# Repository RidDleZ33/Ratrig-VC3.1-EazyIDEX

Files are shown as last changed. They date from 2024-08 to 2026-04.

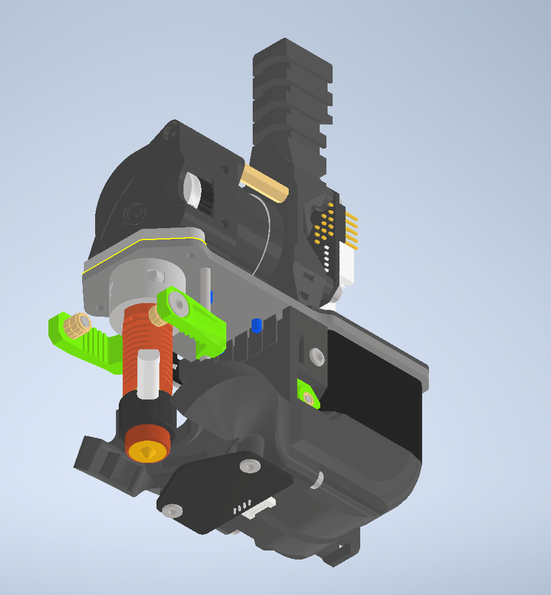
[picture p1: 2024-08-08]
RR_Toolhead_Mods/LGx_Lite_Adapter_MOD/LGx_Lite_REVO3.png

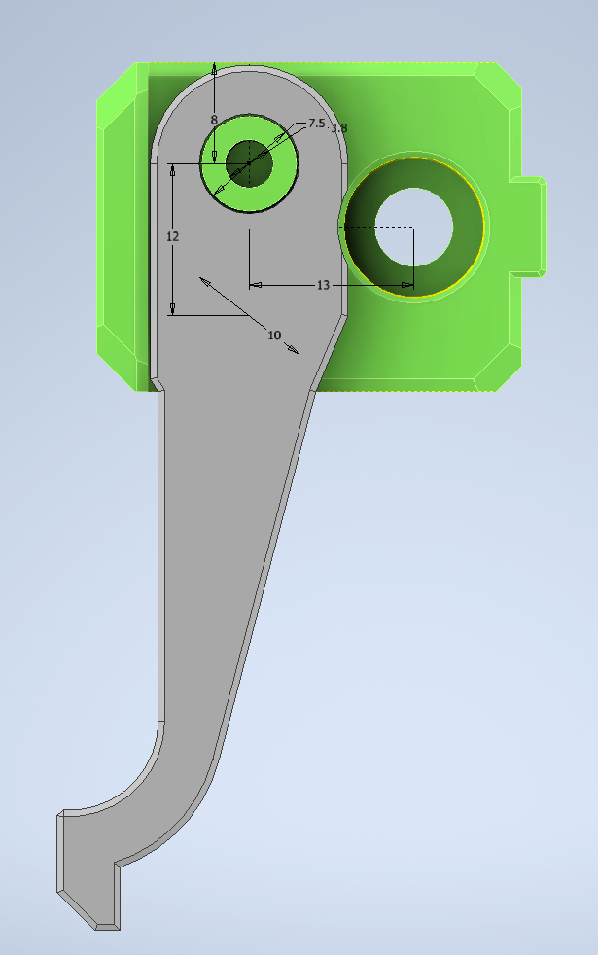
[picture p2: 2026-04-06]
Crossbow_Cutter_Mods/VC4_Depressor/vc4_y_bumper_depressor_v2_1.png

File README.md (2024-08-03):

# Ratrig-VC3.1-EazyIDEX
Modified printed parts for the RatRig V-Core 3.1 printers. Flips the hybrid Y motors to Allow IDEX to be installed without frame modification. I will have two flavors here. .

-STOCK will use modified VC3.1 joiners so the X gantry is 3.1 stock. This way you don't need any new hardware.

-3/4 HYBRID will use the joiners, modified idlers and X gantry from the new VC4 repo. Effecively giving the 3.1 a VC4 hybrid drivetrain. This way you will use all endstops, toolheads, etc from the VC4 IDEX. (note there is clearance issues with the toolhead 'vc4_back' part. I think you can use the vc3_back part from the rr toolhead upgrade repo for the 3.1. I'll update this when I know for sure)

Both options will result in loss of printing volume in the X dimension. The point of this is to easily add IDEX to current VC3.1 units wihout having to modify the frame.

For the aluminum 'plates' I resin print these in eSUN Hard Tough resin. If you can not source them I recommend this.

BOM coming at some point. Only real difference from official Enclosed Vcore 3.1 IDEX BOM is for the motor cage parts I modified:

2x M5x75 cap head screws

2x M5x45 cap head screws

2x M6x20 countersink screw

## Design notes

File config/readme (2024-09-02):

When I went through RatOS 2.1 configurator, I simply told it I have a stock VC3.1 and configured as normal.
After this, you can use my config here as a reference to add the IDEX configs/macros. Everything is done in printer.cfg. NO need to modify any other files.

Here are configs that I've used. The stockVC3.1_printer.cfg is what I use for an Octopus Pro H723. The config is set to use only 1 Y driver (use the parallel Motor2 header and swap a pin in one motor connector), however you can uncomment code and use a combination of the TFT header and EXP1 to wire in an additional driver (this is what I used, you can use any open uart and pins). Good luck!

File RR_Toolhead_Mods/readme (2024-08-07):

Here are notes and mods for the new RR toolhead.

Notes:
These are experimental. I'll update here once I've actually tried them IRL. For now it's all based on assemblies and figuring :)

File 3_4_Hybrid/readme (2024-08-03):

Print quantity notes: 1x unless specified
2x vc4_y_belt_clamp_body
2x vc4_y_belt_clamp_cap
2x vc4_x_endstop
2x vc4_xy_spacer
2x vc4_y_bumper

VC4 gantry on VC3.1

BOM:
14x M3x8 Cap Head Screw
8x M5x60 Countersink Screw
2x M5x30 Low Profile Screw
4x M4x20 Cap Head Screw
4x M4x6 Set Screw
4x M6x12 Cap Head Screw
4x M6 Drop in nut for 3030

6x M3x30 Cap Head Screw

16x F695ZZ Ball Bearing
8x 695ZZ Ball Bearing 
8x M3 Washer
6x M3x4.6x4 Brass Heat Insert

4x M5x22 Countersink Screw

RR toolhead LGx W/REVO
4x M3x6.5 Countersink Screw
4x M3x12 Countersink Screw

VC4 Idler height set: 31.5mm from top of Y belt to top of Alum Extrusion

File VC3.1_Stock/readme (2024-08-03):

Notes:
Parts in the 'Alum' folder are aluminum parts. If you're in a pinch, I found they can be resin printed.

Quantity notes:
2x vc3_idex_motor_plate_v1.0 v2.stl (in Alum folder)
2x PP000128-x_endstop_block_3.1_V01_20230703.stl (If you're upgrading from a non-idex: 1x)

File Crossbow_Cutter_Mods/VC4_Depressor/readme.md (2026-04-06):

# vc4_y_bumper_depressor

Depressor made from modified VC4 Y bumper. use a small washer with the M4 to keep the lever on the body.
on IDEX machines there's plenty of 'room for activities' on either side of the print surface.
the depressor on this is magnetic, this way we can home and probe as usual and the lever simply pushes out of the way.
When a cut opperation needs to happen, simply make a gcode macro that goes around and pull the crossbow lever.
disclaimer, be sure the order of homing, etc never comes at the lever from the depressing side.
Usually this isn't a probem because of the extra space on IDEX. extra caution on non idex machines.

BOM:
2x 10x4 magnets (common ratrig enclosure panel mounting, etc.)
1x M4x6mm ~ fastener

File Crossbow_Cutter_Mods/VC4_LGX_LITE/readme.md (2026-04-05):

# Crossbow CNC VC4_LGX_LITE_UNI

Modified crossbow body and holder for Ratrig VC4 LGX Lite adapter toolheads. Simply buy a CNC crossbow and put all hardware on this printed variant.
Handle can be mounted on either side for T1 or T0 heads. Still easilly replace razor. printed in PETG and have over 100 cuts with no issues so far, though I plan to print in Nylon eventually.
requires one extra part: M2.5 x 5mm ~ fastener for handle. I've used countersunk and caphead, doesn't matter. just needs to hold the sandwich together at the handle for less flex.

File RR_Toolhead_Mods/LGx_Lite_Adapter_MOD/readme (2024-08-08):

This plate will adapt an LGx_Lite extruder to the new RR toolhead.

BOM:
1x adapter (I resin printed it, but I'm sure you could FDM print)
1x toolboard_vertical mount for attaching to extruder
1x M3x30 cap head screw for enough thread to screw on standoff
1x M3x8 cap head screw for attaching toolboard mount to standoff
4x M3x8 countersink head screws
2x M3x8 cap head screws (stock ones for mounting orbiter)

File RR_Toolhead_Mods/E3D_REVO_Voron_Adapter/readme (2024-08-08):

This plate mounts the E3D REVO hotend on the new RR toolhead. Luckily the REVO heatbreak is so much shorter than the rapido, that there's room to use the space to make an adapter.

BOM:
1x REVO_Adapter
4x M2.5x12 countersink head screws
4x M2.5 Nylock Hex Nut
4x M3x18 countersink head screws

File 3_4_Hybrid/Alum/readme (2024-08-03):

Parts here are Aluminum. You can also resin print them. I recommend eSUN Hard Tough Resin.

Quantity notes:
1x EazyIDEX tensioner body left
1x EazyIDEX tensioner body right
2x vc3_idex_motor_plate
4x vc4_tensioner_arm
2x vc4_xy_joiner_lower
2x vc4_xy_joiner_middle
2x vc4_xy_joiner_upper

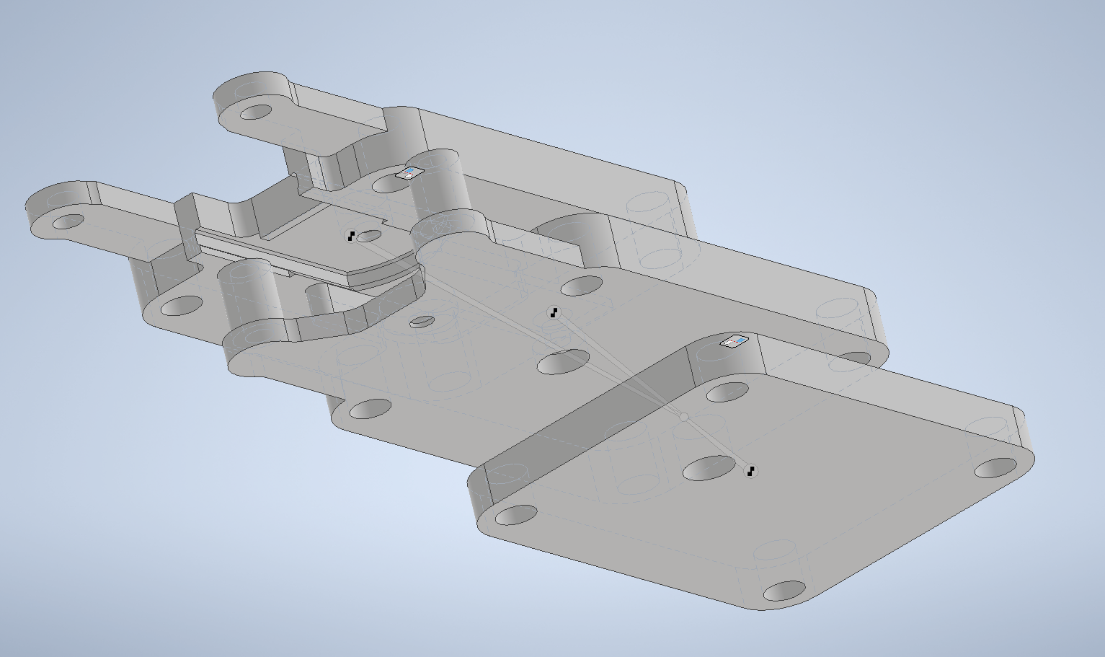
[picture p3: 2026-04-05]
Crossbow_Cutter_Mods/VC4_LGX_LITE/Cutter_VC4_LGX_LITE_ASSY3.png

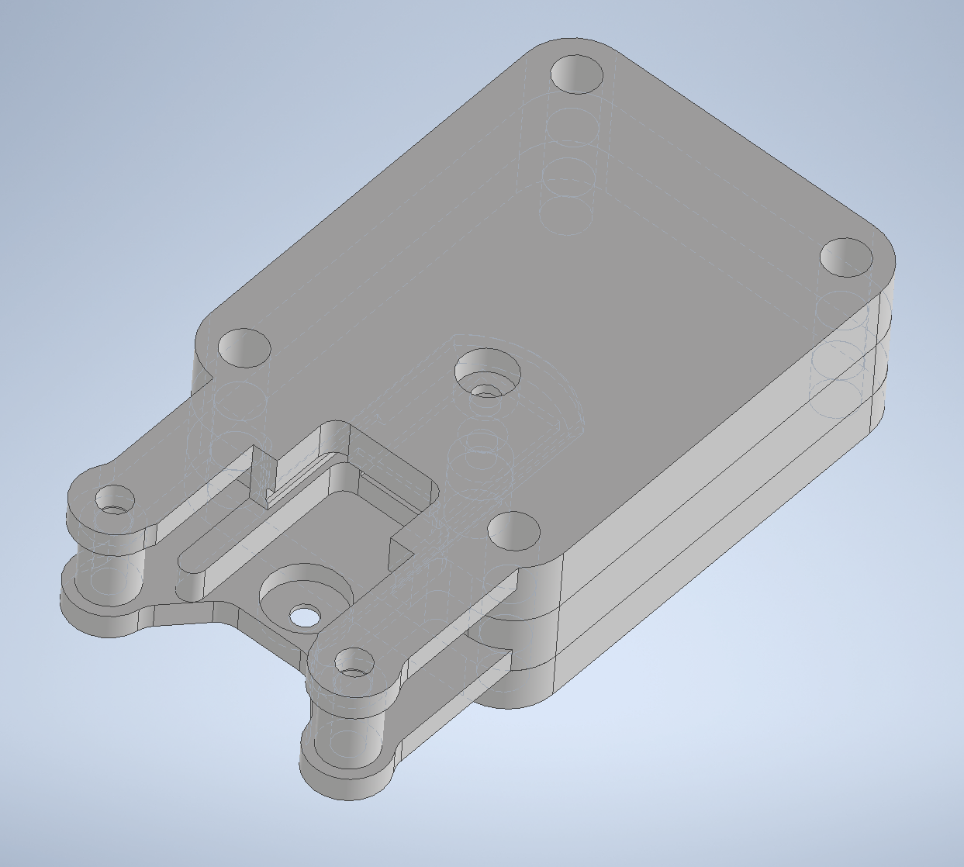
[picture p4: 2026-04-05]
Crossbow_Cutter_Mods/VC4_LGX_LITE/Cutter_VC4_LGX_LITE_ASSY1.png

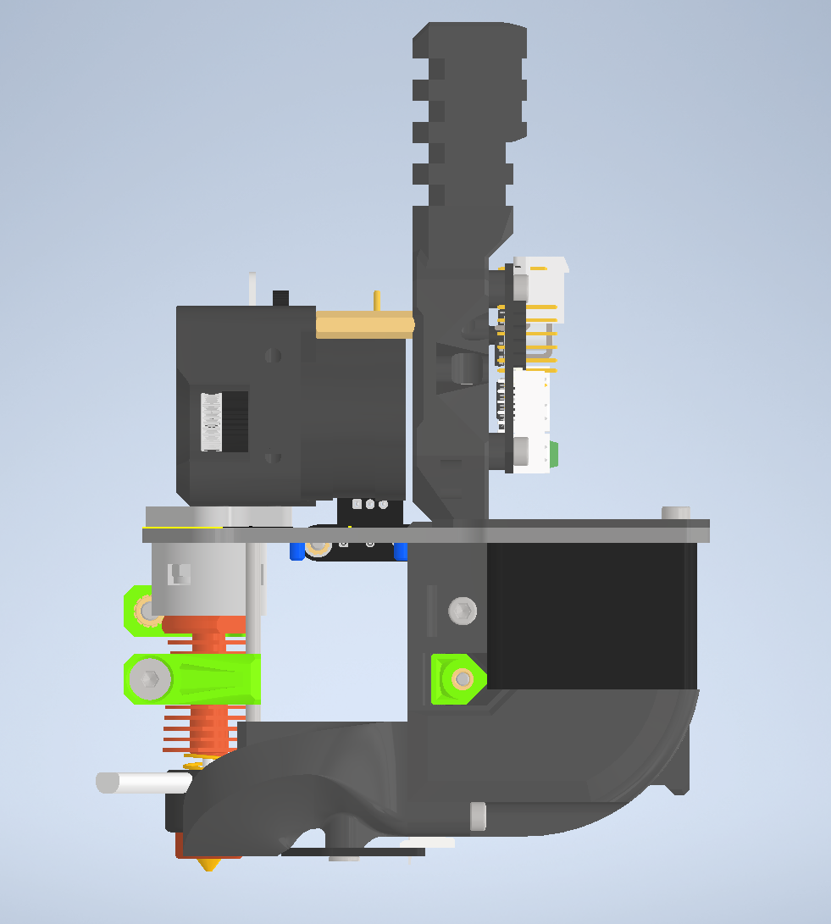
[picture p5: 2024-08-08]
RR_Toolhead_Mods/LGx_Lite_Adapter_MOD/LGx_Lite_REVO2.png

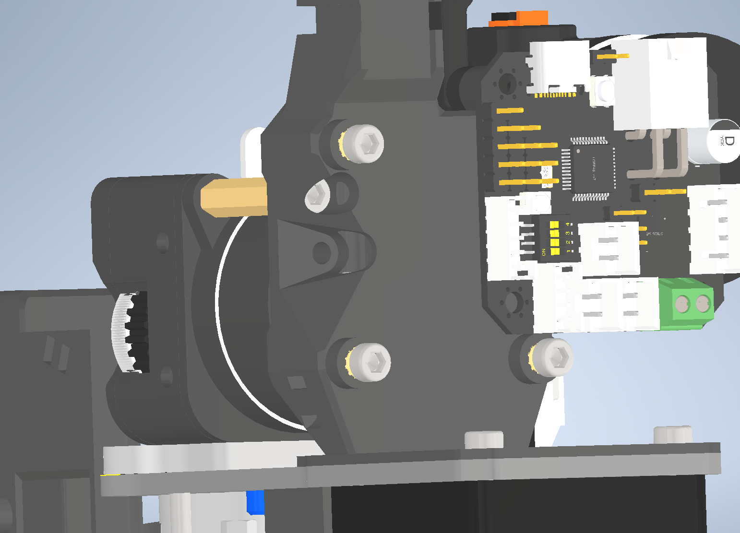
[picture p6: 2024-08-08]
RR_Toolhead_Mods/LGx_Lite_Adapter_MOD/LGx_Lite_ToolboardMnt.png

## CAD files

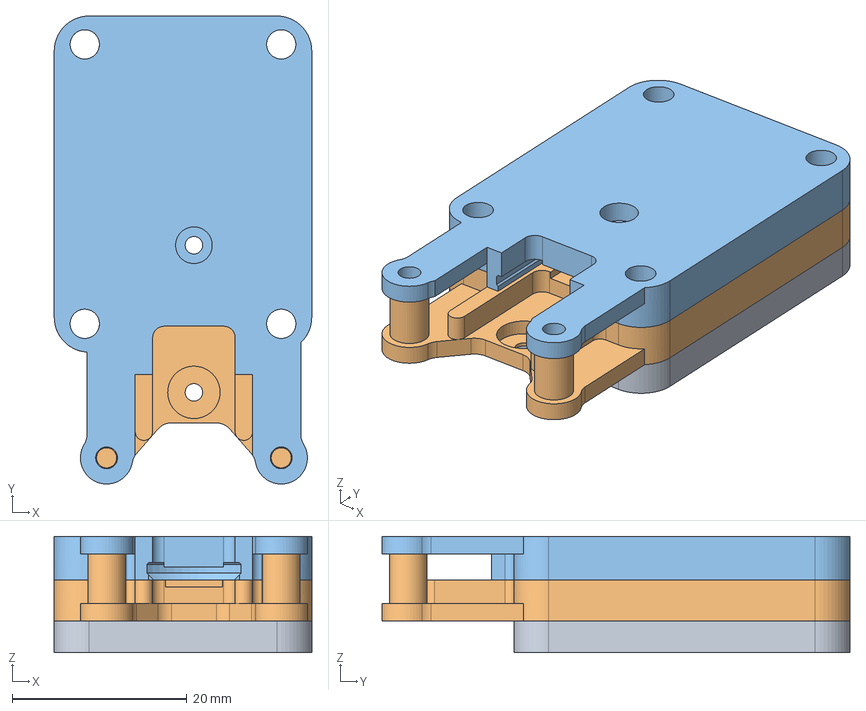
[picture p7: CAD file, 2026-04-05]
Crossbow_Cutter_Mods/VC4_LGX_LITE/cad/Crossbow CNC VC4_LGX_LITE_UNI_V2_assy.stp
29.5 x 53.6 x 13.3 mm
Crossbow CNC VC4_T1_spacer_v2
Crossbow CNC VC4_T1_Assy_simplified_V2
Crossbow CNC VC4_T1_holder_V2

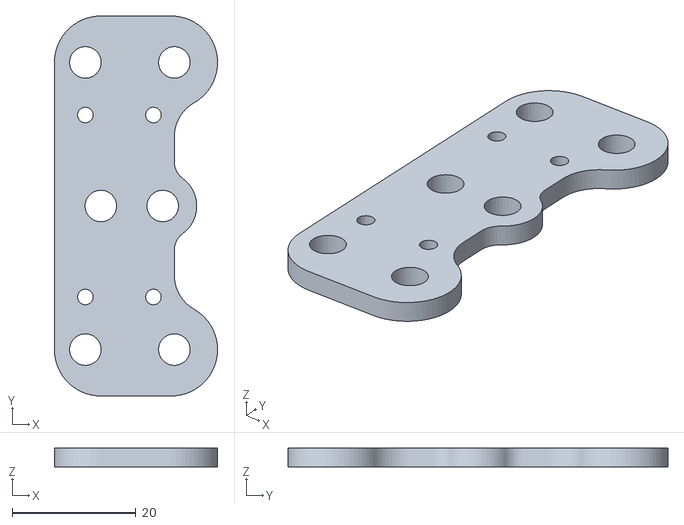
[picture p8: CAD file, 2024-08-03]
3_4_Hybrid/Alum/vc4_xy_joiner_lower_v1.1 v1.stl
26.4 x 61.4 x 3.00

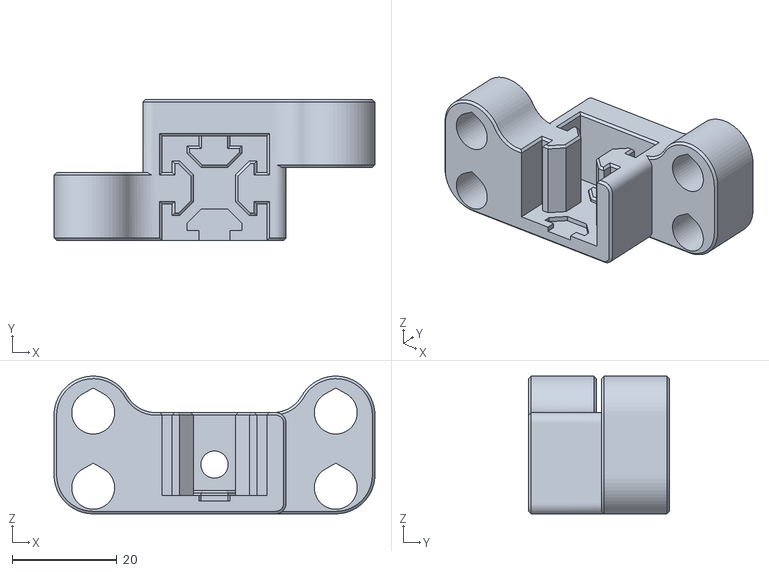
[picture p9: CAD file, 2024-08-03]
3_4_Hybrid/vc4_xy_spacer v2.stl
61.4 x 27.0 x 26.4

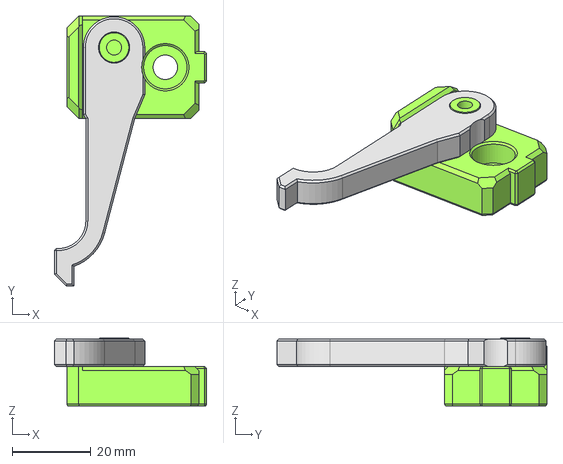
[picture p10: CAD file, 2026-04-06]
Crossbow_Cutter_Mods/VC4_Depressor/cad/vc4_y_bumper_depressor_v2.stp
38.7 x 68.5 x 17.2 mm

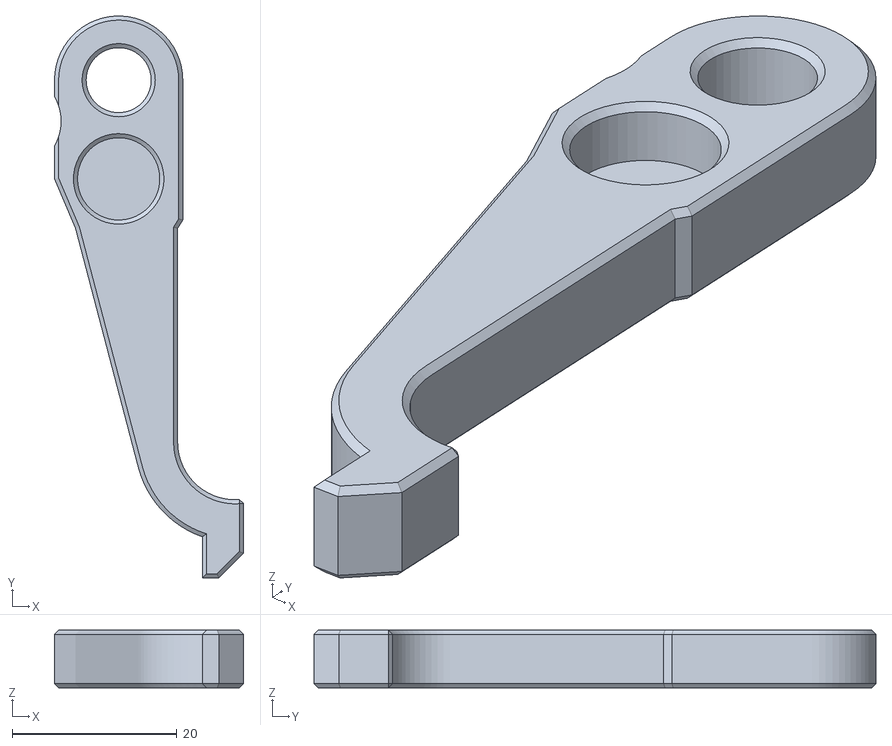
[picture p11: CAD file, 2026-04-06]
Crossbow_Cutter_Mods/VC4_Depressor/vc4_y_bumper_depressor_lever_v2.stl
23.0 x 68.3 x 7.00

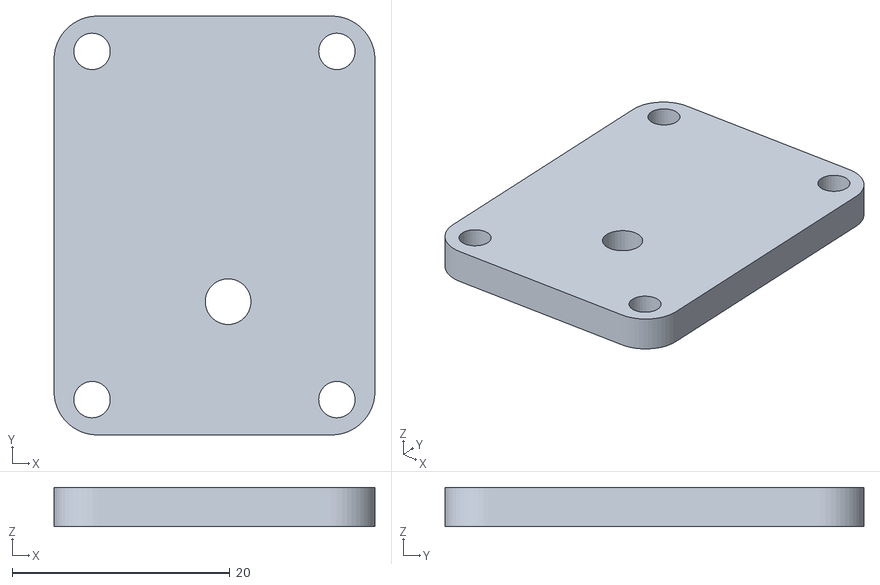
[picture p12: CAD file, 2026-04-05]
Crossbow_Cutter_Mods/VC4_LGX_LITE/Crossbow CNC VC4_LGX_LITE_UNI_V2_Spacer.stl
29.5 x 38.5 x 3.60

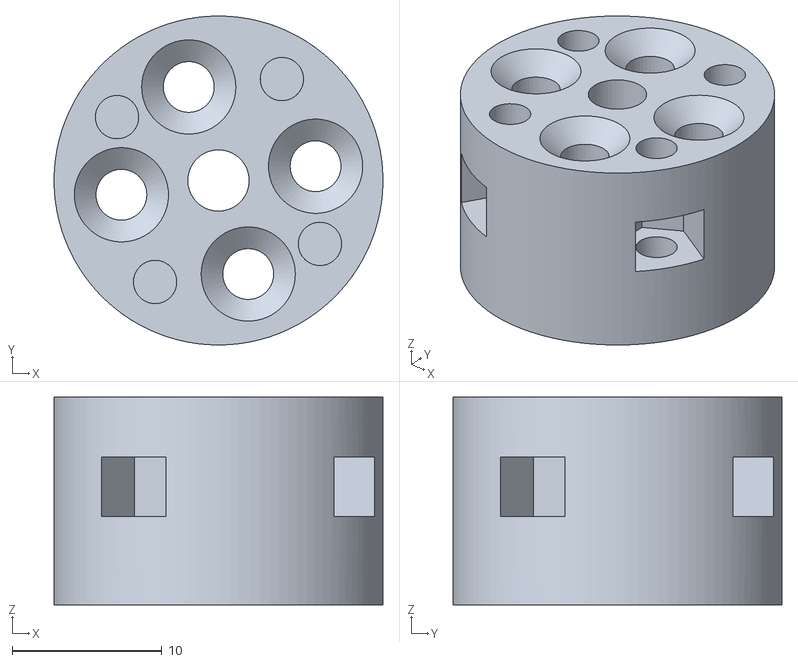
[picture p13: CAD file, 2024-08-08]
RR_Toolhead_Mods/E3D_REVO_Voron_Adapter/Revo_Voron_RR Toolhead Adapter.stl
22.0 x 22.0 x 13.9

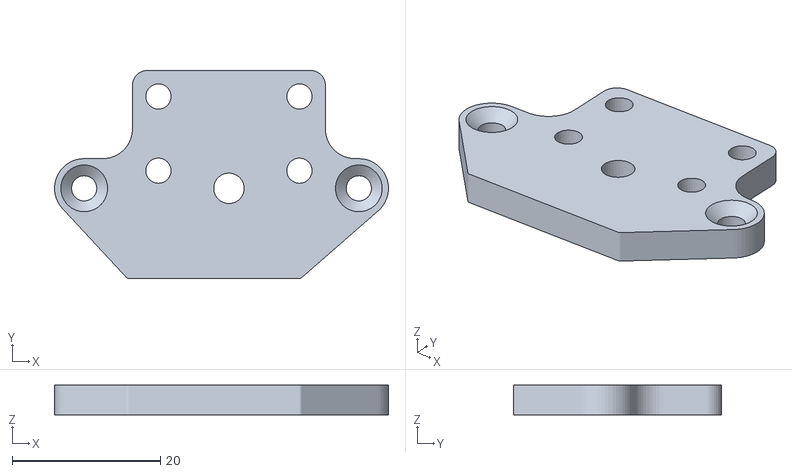
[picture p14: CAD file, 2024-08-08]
RR_Toolhead_Mods/LGx_Lite_Adapter_MOD/LGx_Lite_Adapter_RR Toolhead Plate.stl
45.0 x 28.0 x 4.00

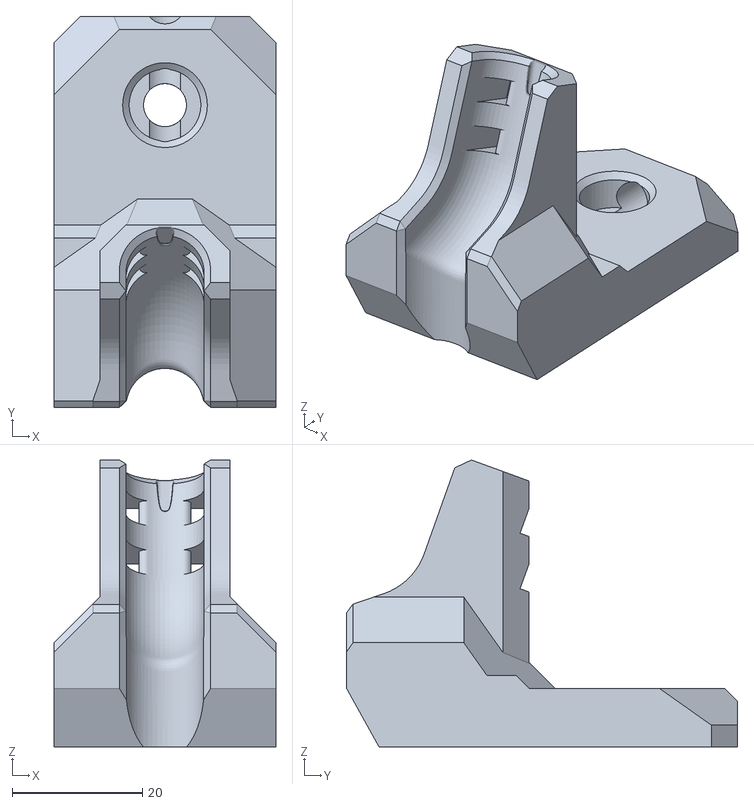
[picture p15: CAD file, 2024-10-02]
VC3.1_Stock/vc4_vc3_MOD_umbilical_frame.stl
34.0 x 60.0 x 44.0

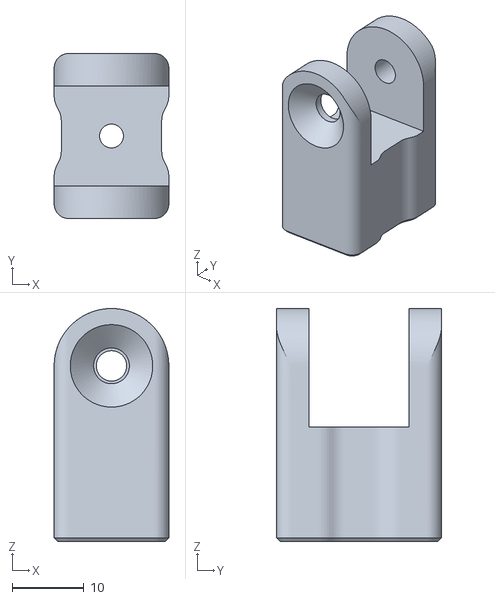
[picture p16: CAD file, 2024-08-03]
3_4_Hybrid/Alum/vc4_tensioner_arm_v1.0 v1.stl
16.0 x 23.0 x 32.5

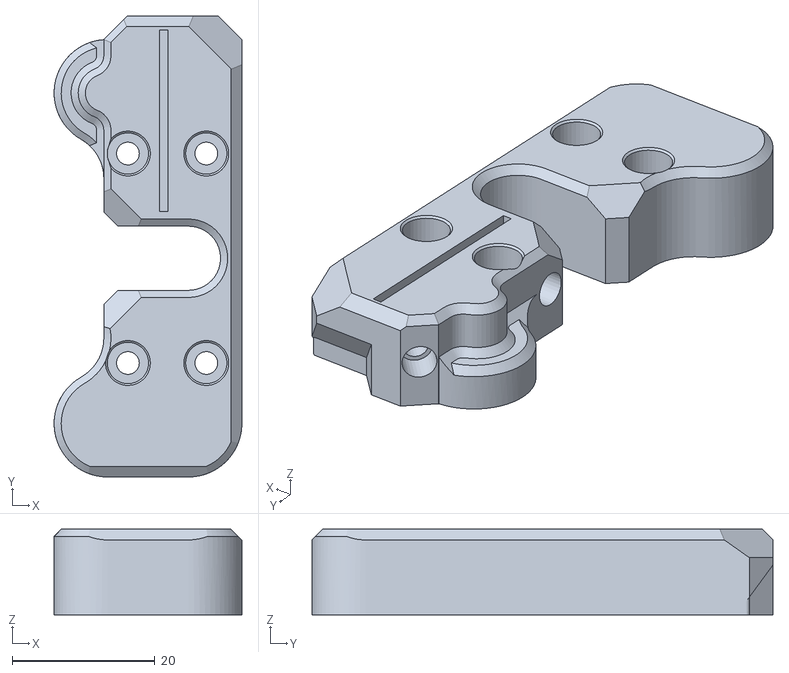
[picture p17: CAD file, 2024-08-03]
3_4_Hybrid/vc4_xy_trim_right.stl
26.4 x 64.7 x 12.0

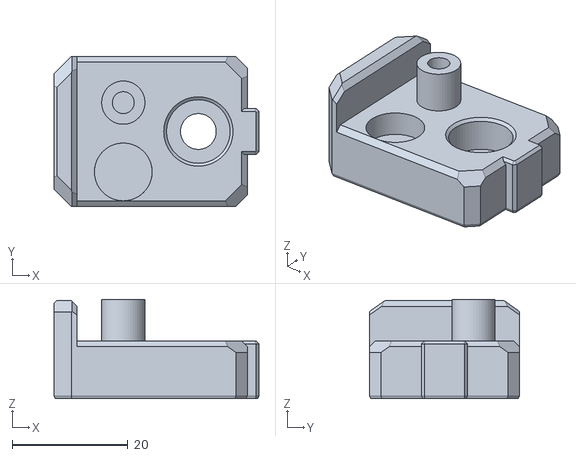
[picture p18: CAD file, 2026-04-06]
Crossbow_Cutter_Mods/VC4_Depressor/vc4_y_bumper_depressor_body_v2.stl
35.5 x 26.0 x 17.2

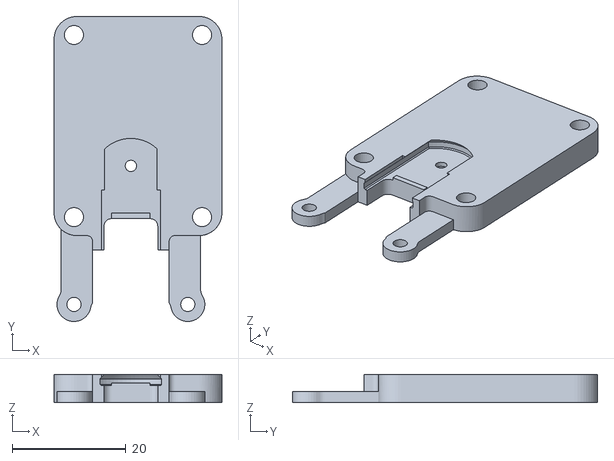
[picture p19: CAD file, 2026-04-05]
Crossbow_Cutter_Mods/VC4_LGX_LITE/Crossbow CNC VC4_LGX_LITE_UNI_V2_Holder.stl
29.5 x 53.6 x 5.00

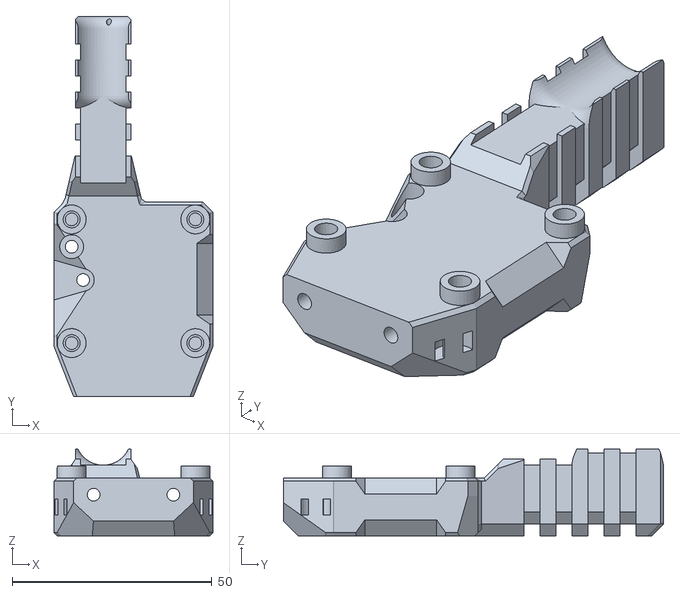
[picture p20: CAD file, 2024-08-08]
RR_Toolhead_Mods/LGx_Lite_Adapter_MOD/LGx_Lite_Adapter_rr_toolhead_vc4_toolboard_vertical v2.stl
39.9 x 95.4 x 21.7

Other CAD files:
3_4_Hybrid/Alum/vc4_xy_joiner_upper_v1.1 v1.stl
3_4_Hybrid/vc4_xy_trim_left.stl
Crossbow_Cutter_Mods/VC4_LGX_LITE/Crossbow CNC VC4_LGX_LITE_UNI_V2_Body.stl
VC3.1_Stock/EazyIDEX_enclosure2_xy_idlers_right_idex_3.1.stl
3_4_Hybrid/Alum/EazyIDEX34_vc4_tensioner_body_left_v1.0 v1.stl
3_4_Hybrid/Alum/EazyIDEX34_vc4_tensioner_body_right_v1.0 v1.stl
3_4_Hybrid/Alum/vc3_idex_motor_plate_v1.0 v2.stl
3_4_Hybrid/Alum/vc4_xy_joiner_middle_v1.1 v1.stl
3_4_Hybrid/EazyIDEX_Enclosure2_xy_motor_cage_idex_top_left_3.1.stl
3_4_Hybrid/EazyIDEX_Enclosure2_xy_motor_cage_idex_top_right_3.1.stl
3_4_Hybrid/EazyIDEX_y_motor_cage_idex_bottom_left.stl
3_4_Hybrid/EazyIDEX_y_motor_cage_idex_bottom_right.stl
3_4_Hybrid/EazyIDEX_y_motor_cage_idex_top_left.stl
3_4_Hybrid/EazyIDEX_y_motor_cage_idex_top_right.stl
3_4_Hybrid/vc4_x_endstop v1.stl
3_4_Hybrid/vc4_y_belt_clamp_body.stl
3_4_Hybrid/vc4_y_belt_clamp_cap.stl
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

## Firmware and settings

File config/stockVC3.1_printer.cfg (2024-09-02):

#############################################################################################################
### CONFIGURATION GENERATED BY THE RATOS CONFIGURATOR
#############################################################################################################
[include RatOS.cfg]
##IDEX MOD
[include RatOS/printers/v-core-3-idex/v-core-3.cfg]
[include RatOS/printers/v-core-3-idex/500.cfg]
[include RatOS/printers/v-core-3-idex/macros.cfg]
#[include RatOS/macros/idex/toolheads.cfg]
#[include RatOS/macros/idex/idex.cfg]
#[include RatOS/macros/idex/overrides.cfg]
#[include RatOS/macros.cfg]

#############################################################################################################
### MACRO CONFIGURATION
### Configure the behavior of RatOS macros
### See: https://os.ratrig.com/docs/configuration/macros
#############################################################################################################
[gcode_macro RatOS]
variable_relative_extrusion: True
variable_preheat_extruder: True
variable_calibrate_bed_mesh: True
variable_nozzle_priming: "primeblob"
variable_nozzle_prime_start_x1:420
#variable_printable_x_max:420
variable_start_print_park_in: "back"
variable_start_print_park_z_height: 50
variable_end_print_park_in: "back"
variable_pause_print_park_in: "back"
variable_macro_travel_speed: 600
variable_macro_travel_accel: 8000

#############################################################################################################
### USER OVERRIDES & CUSTOM CONFIGURATION
### Anything custom you want to add, or RatOS configuration you want to override, do it here.
### This section is pre-populated with the most common settings you may want to change.
### See: https://os.ratrig.com/docs/configuration/includes-and-overrides
###
### It is recommended that you follow these steps to properly calibrate your printer:
### 0) Sanity check and PID Tuning: https://www.klipper3d.org/Config_checks.html
### 1) Z-offset calibration: https://www.klipper3d.org/Probe_Calibrate.html#calibrating-probe-z-offset
### 2) Pressure Advance: https://www.klipper3d.org/Pressure_Advance.html
### 3) Skew Correction: https://www.klipper3d.org/Skew_Correction.html
### 4) Resonance Compensation: https://www.klipper3d.org/Resonance_Compensation.html
### RatOS has dedicated macro's to generate shaper graphs for deeper analysis (requires accelerometer).
### Use MEASURE_COREXY_BELT_TENSION to compare tension between belts, and use
### GENERATE_SHAPER_GRAPHS to generate the resonance graphs for analysing and manually entering input shaper
### configuration.
### You can run SHAPER_CALIBRATE to automatically calibrate your input shaper configuration, if you just want
### to get started.
### Additionally, you can use the Realtime Analysis Tool to analyze your printer's performance in real-time.
### Read more about klipper here: https://www.klipper3d.org/Overview.html
#############################################################################################################

#---------------------------------------------------- X -----------------------------------------------------
# The A motor in the CoreXY system, located at the rear left of the printer
#------------------------------------------------------------------------------------------------------------
[tmc2209 stepper_x]
stealthchop_threshold: 0
interpolate: False
uart_pin: PC4
run_current: 1.6
driver_TBL: 1
driver_TOFF: 3
driver_HEND: 0
driver_HSTRT: 0
sense_resistor: 0.11

[stepper_x]
step_pin:PF13
dir_pin:PF12              # Add ! in front of pin name to reverse the direction of stepper_x
enable_pin:!PF14
#uart_pin:PC4
#diag_pin:PG6
endstop_pin:PG6           
rotation_distance: 40     # 40 for 20 tooth 2GT pulleys, 32 for 16 tooth 2GT pulleys
homing_speed: 50
position_min: 0
position_max: 420
position_endstop: 0

[tmc2209 dual_carriage]
stealthchop_threshold: 0
interpolate: False
uart_pin: PD11
run_current: 1.6
driver_TBL: 1
driver_TOFF: 3
driver_HEND: 0
driver_HSTRT: 0
sense_resistor: 0.11

[dual_carriage]
step_pin:PG0
dir_pin:PG1
enable_pin:!PF15
#uart_pin:PD11
#diag_pin:PG10
endstop_pin:PG10
rotation_distance: 40
homing_speed: 50
microsteps: 64
position_max: 500
position_endstop: 500
position_min: 60

#---------------------------------------------------- Y -----------------------------------------------------
# The B motor in the CoreXY system, located at the rear right of the printer
#------------------------------------------------------------------------------------------------------------

[tmc2209 stepper_y]
stealthchop_threshold: 0
interpolate: False
uart_pin: PC6
run_current: 1.6
driver_TBL: 1
driver_TOFF: 3
driver_HEND: 0
driver_HSTRT: 0
sense_resistor: 0.11

[stepper_y]
step_pin:PF11
dir_pin:!PG3               # Add ! in front of pin name to reverse the direction of stepper_y
enable_pin:!PG5
endstop_pin:PG9      
rotation_distance: 40     # 40 for 20 tooth 2GT pulleys, 32 for 16 tooth 2GT pulleys
homing_speed: 50
position_min: 0
position_max: 500
position_endstop: 500

#[tmc2209 stepper_y1]  #uncomment if you have wired in 9th driver or your controller supports more than 8
#stealthchop_threshold: 0
#interpolate: False
#uart_pin: PA9
#run_current: 1.6
#driver_TBL: 1
#driver_TOFF: 3
#driver_HEND: 0
#driver_HSTRT: 0
#sense_resistor: 0.11

#[stepper_y1]  #uncomment if you have wired in 9th driver or your controller supports more than 8
#step_pin:PE9
#dir_pin:PE12               # Add ! in front of pin name to reverse the direction of stepper_y
#enable_pin:!PE8
#endstop_pin:PG9      
#rotation_distance: 40     # 40 for 20 tooth 2GT pulleys, 32 for 16 tooth 2GT pulleys
#microsteps: 64

#---------------------------------------------------- Z -----------------------------------------------------
# The left Z motor for the kinematic bed
#------------------------------------------------------------------------------------------------------------
[stepper_z]
dir_pin: !z0_dir_pin      # Remove ! in front of pin name to reverse the direction of stepper_z
rotation_distance: 4      # 4 for TR8*4 lead screws
homing_speed: 10
position_min: -5
position_max: 500
[tmc2209 stepper_z]
run_current: 1.1

#---------------------------------------------------- Z1 ----------------------------------------------------
# The rear Z motor for the kinematic bed
#------------------------------------------------------------------------------------------------------------
[stepper_z1]
dir_pin: !z1_dir_pin      # Remove ! in front of pin name to reverse the direction of stepper_z1
rotation_distance: 4      # 4 for TR8*4 lead screws
[tmc2209 stepper_z1]
run_current: 1.1


#---------------------------------------------------- Z2 ----------------------------------------------------
# The right Z motor for the kinematic bed
#------------------------------------------------------------------------------------------------------------
[stepper_z2]
dir_pin: !z2_dir_pin      # Remove ! in front of pin name to reverse the direction of stepper_z2
rotation_distance: 4      # 4 for TR8*4 lead screws
[tmc2209 stepper_z2]
run_current: 1.1

#------------------------------------------------- EXTRUDER -------------------------------------------------
# The extruder motor used for pushing filament through the toolhead
#------------------------------------------------------------------------------------------------------------
[extruder]
dir_pin: e_dir_pin       # Remove ! in front of pin name to reverse the direction of extruder
rotation_distance: 5.57   # Bondtech LGX Lite default
pressure_advance: 0.06   # Check https://www.klipper3d.org/Pressure_Advance.html for pressure advance tuning.
control: pid
pid_kp: 28.413
pid_ki: 1.334
pid_kd: 151.300

[tmc2209 extruder1]
stealthchop_threshold: 0
interpolate: False
uart_pin: PF2
run_current: 0.707
driver_TBL: 0
driver_TOFF: 4
driver_HEND: 6
driver_HSTRT: 7
sense_resistor: 0.11

[extruder1]
step_pin:PF9
dir_pin:PF10
enable_pin:!PG2
microsteps:64
rotation_distance: 5.57
full_steps_per_rotation: 200
filament_diameter: 1.750
max_extrude_only_velocity: 120
max_extrude_only_accel: 800
pressure_advance_smooth_time: 0.02
# T1 E3D V6 definition (from RatOS/hotends/v6.cfg)
max_extrude_only_distance: 200
nozzle_diameter: 0.4
heater_pin: PA3
max_power:0.5
sensor_type: ATC Semitec 104GT-2
sensor_pin: PF5
control: pid
pid_kp: 28.413
pid_ki: 1.334
pid_kd: 151.300
min_extrude_temp: 170
min_temp: 0
max_temp: 285
pressure_advance: 0.06

# printer max velocity settings
[printer]
max_velocity: 600
max_accel: 15000
#max_accel_to_decel: 7500
max_z_velocity: 20
max_z_accel: 150
#square_corner_velocity: 10

[dual_carriage]
safe_distance: 70

[exclude_object]

#[adxl345]
#spi_software_sclk_pin: PB3
#spi_software_mosi_pin: PB5
#spi_software_miso_pin: PB4
#cs_pin: PA15


[heater_bed]
control: pid
pid_Kp: 22.2
pid_Ki: 1.08
pid_Kd: 114
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

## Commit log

2024-07-27 Add files via upload
    added STOCK variant EazyIDEX STL's
    [EazyIDEX_Enclosure2_xy_motor_cage_idex_top_left_3.1.stl, EazyIDEX_Enclosure2_xy_motor_cage_idex_top_right_3.1.stl, EazyIDEX_enclosure2_xy_idlers_left_idex_3.1.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]
2024-08-03 Add files via upload
    Fixed counterbore hole for idler
    [EazyIDEX_Enclosure2_xy_motor_cage_idex_top_left_3.1.stl, EazyIDEX_Enclosure2_xy_motor_cage_idex_top_right_3.1.stl]
2024-09-02 Create stockVC3.1_printer.cfg
    my printer.cfg for running IDEX with Octopus Pro H723
    [stockVC3.1_printer.cfg]
2024-10-02 Add files via upload
    Modded from original VC4_umbilical_frame to allow fitment on VC3.1 printers. I've added an M3 hex nut slot you can insert from the bottom for locking down the piano wire. The brass press-in would not work with this design.
    [vc4_vc3_MOD_umbilical_frame.stl]
2026-04-05 add crossbow VC4 LGX mod
    add photos and cad/stl files for universal (T0/T1) crossbow cutter body and holder. For use with LGX Lite adapter for VC4 Toolheads.
    [Crossbow CNC VC4_LGX_LITE_UNI_V2_Body.stl, Crossbow CNC VC4_LGX_LITE_UNI_V2_Holder.stl, Crossbow CNC VC4_LGX_LITE_UNI_V2_Spacer.stl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]
2026-04-05 upload lgx lite cad
    [Crossbow CNC VC4_LGX_LITE_UNI_assy.iam, Crossbow CNC VC4_LGX_LITE_UNI_body_v2.ipt, Crossbow CNC VC4_LGX_LITE_UNI_holder_V2.ipt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]
2026-04-06 add depressor files and readme
    modded vc4 y bumper depressor for crossbow cutter.
    [vc4_y_bumper_depressor_body_v2.stl, vc4_y_bumper_depressor_lever_v2.stl, vc4_y_bumper_depressor_v2.ipt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]
